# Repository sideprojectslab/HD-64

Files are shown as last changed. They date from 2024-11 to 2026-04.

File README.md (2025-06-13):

# HD-64

To **REPORT ISSUES** or to simply get in touch with the developer, please join the SPL [Discord](https://discord.gg/gJsCgebkDw) server.

[FULL README (PDF)](https://raw.githubusercontent.com/sideprojectslab/HD-64/main/doc/README.pdf)

HD-64 is an RF-modulator replacement for the Commodore-64 computer which features a Full-HD 50/60Hz Micro-HDMI video+audio output. Crucially, the HD-64 is not a replacement for the VIC-II, which still needs to be mounted on the motherboard

Instead of digitizing the VIC's analog video output signal, the HD-64 "sniffs" the C64's memory bus and recreates a pixel-perfect video output by means of emulation implemented on FPGA. The reconstructed video is then upscaled to Full-HD resolution, merged with the digitized audio from the SID, and sent out as HDMI.

<figure align="center" id="HD-64">
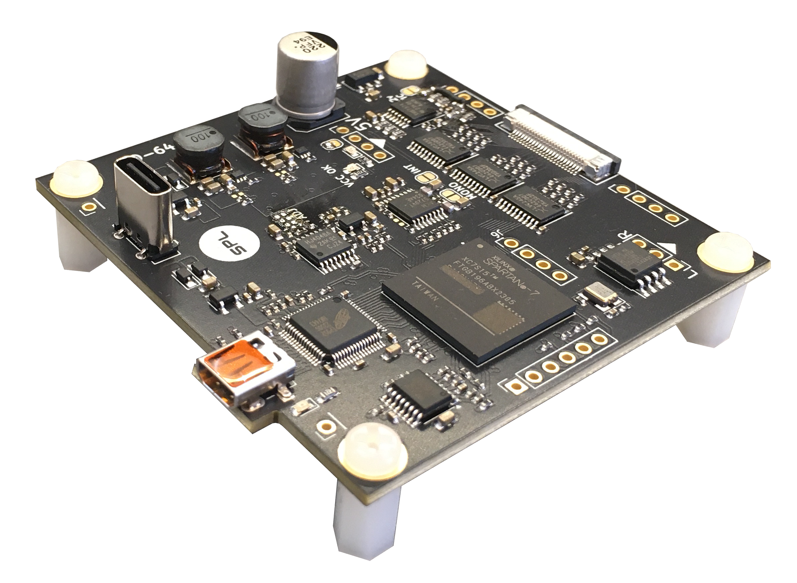
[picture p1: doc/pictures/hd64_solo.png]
	
	<figcaption>HD-64 Main Board</figcaption>
</figure>

<figure align="center" id="hd64_shortboard_back">
	
	<figcaption>HD-64 Short-Board Assembly</figcaption>
</figure>

<figure align="center" id="hd64_longboard">
	
	<figcaption>HD-64 Long-Board Assembly</figcaption>
</figure>

# 1. License
License information is included on top of all software source files as well as in all schematics. Files that do not contain explicit licensing information are subject to the licensing terms stated in the LICENSE.txt provided in the main project folder:

Unless stated otherwise in individual files, all hardware design Schematics, Bill of Materials, Gerber files and manuals are licensed under Creative Commons Attribution-NonCommercial-NoDerivatives 4.0 International. To view a copy of this license, visit http://creativecommons.org/licenses/by-nc-nd/4.0/

Unless otherwise stated in individual files, all software source files are Licensed under the Apache License, Version 2.0. You may obtain a copy of this license at http://www.apache.org/licenses/LICENSE-2.0

# 2. Disclaimer
All material is provided on an 'AS IS' BASIS, WITHOUT WARRANTIES OR CONDITIONS OF ANY KIND in accordance to the license deed applicable to each individual file.

# 3. Contributing
The only open source portion of the HD-64 firmware is the VIC-II emulation written in VHDL, with the rest of the source code not being made available. Even so, **anyone can contribute to changes to the VIC-II emulator, build and test the results without having to access the entire codebase, nor having to set up a local build system**. Builds run directly on the SPL build server and compilation outputs are delivered back to the developers through dedicated GitHub releases. Please find the [Developer's Guide](https://raw.githubusercontent.com/sideprojectslab/HD-64/main/doc/dev_guide.pdf) for detailed information on how to contribute to the project.

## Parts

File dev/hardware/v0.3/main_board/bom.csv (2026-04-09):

Comment | DNP | Designator | Footprint
GRM155R71H104KE14D |  | C1, C2, C3, C6, C10, C12, C14, C19, C26, C27, C28, C29, C30, C31, C32, C33, C37, C40, C44, C45, C53, C59, C62, C63, C64, C69, C72, C79, C80, C81, C82, C83, C85, C90, C94 | eas_cdb_capacitor:C_0402_1005Metric
GRM188R61A106ME69D |  | C4, C5, C7, C11, C13, C15, C16, C17, C23, C24, C25, C36, C41, C46, C48, C49, C52, C55, C56, C58, C68, C71, C76, C77, C78, C84, C86, C97, C98 | eas_cdb_capacitor:C_0603_1608Metric
C1608C0G1H103JT000N |  | C8, C9 | eas_cdb_capacitor:C_0603_1608Metric
GRM155R61C105KE01D |  | C18, C20, C21, C35, C39, C42, C60, C65, C67, C70, C73, C74, C75 | eas_cdb_capacitor:C_0402_1005Metric
GRM155R61A474KE15D |  | C34, C38, C61 | eas_cdb_capacitor:C_0402_1005Metric
EEE-FP1V221AP |  | C51 | eas_cdb_capacitor:CP_Elec_8x6.9
CL21A476MQYNNNG |  | C66, C87, C88, C89, C91, C92 | eas_cdb_capacitor:C_0805_2012Metric
GCM1555C1H100JA16D |  | C96 | eas_cdb_capacitor:C_0402_1005Metric
B5817WS |  | D1, D3, D5, D8, D9 | eas_cdb_diode:D_SOD-323_HandSoldering
LTST-C191KGKT |  | D2, D6, D10 | eas_cdb_opto:LED_0603_1608Metric
AFC07-S24FCA-00 |  | J1 | eas_cdb_connector_generic:AFC07-S24FCA-00
TYPE-C 16P LTH8.8 |  | J4 | eas_cdb_connector_generic:CONN_GSB1CA11101DSHR_AMP
HDMI-101L |  | J11 | eas_cdb_connector_generic:HDMI_Micro-D_Molex_46765-2x0x
FNR6045S100MT |  | L1, L2 | eas_cdb_inductor:IND_1255AY-xRxN=P3
DMP1045U-7 |  | Q1 | eas_cdb_mosfet:SOT-23
RC0402FR-0722RL |  | R1, R2, R11, R12, R63, R70, R107, R126, R127 | eas_cdb_resistor:R_0402_1005Metric
RC0402FR-0710KL |  | R3, R8, R13, R17, R21, R22, R30, R31, R32, R35, R41, R42, R45, R46, R52, R53, R57, R58, R60, R61, R62, R71, R114, R115, R116, R122, R123, R124, R125 | eas_cdb_resistor:R_0402_1005Metric
RC0402FR-072K2L |  | R4, R5, R39, R40, R48, R51, R98, R103, R105, R106 | eas_cdb_resistor:R_0402_1005Metric
RC0603FR-073K3L |  | R6 | eas_cdb_resistor:R_0603_1608Metric
RC0603FR-07680RL |  | R7, R28, R65 | eas_cdb_resistor:R_0603_1608Metric
RC0603FR-07270RL |  | R9, R128 | eas_cdb_resistor:R_0603_1608Metric
RC0603FR-07470RL |  | R10 | eas_cdb_resistor:R_0603_1608Metric
RC0402FR-075K1L |  | R14, R18 | eas_cdb_resistor:R_0402_1005Metric
RC0402FR-07100KL |  | R15 | eas_cdb_resistor:R_0402_1005Metric
RC0603FR-07220RL |  | R19 | eas_cdb_resistor:R_0603_1608Metric
RC0402FR-071KL |  | R23, R24, R36, R96, R97, R99, R100, R101, R108 | eas_cdb_resistor:R_0402_1005Metric
RC0603FR-0775RL |  | R25, R26, R27 | eas_cdb_resistor:R_0603_1608Metric
RC0402FR-076K8L |  | R29 | eas_cdb_resistor:R_0402_1005Metric
RC0402FR-074K7L |  | R33, R34, R104 | eas_cdb_resistor:R_0402_1005Metric
RC0402FR-07820RL |  | R37 | eas_cdb_resistor:R_0402_1005Metric
RC0402FR-0747KL |  | R38, R44, R47 | eas_cdb_resistor:R_0402_1005Metric
RC0402FR-072M2L |  | R43 | eas_cdb_resistor:R_0402_1005Metric
RC0402FR-0733KL |  | R50 | eas_cdb_resistor:R_0402_1005Metric
0402WGF1213TCE |  | R54 | eas_cdb_resistor:R_0402_1005Metric
RC0402FR-0727KL |  | R55 | eas_cdb_resistor:R_0402_1005Metric
RC0603FR-071KL |  | R64, R68 | eas_cdb_resistor:R_0603_1608Metric
RC0603FR-07330RL |  | R66 | eas_cdb_resistor:R_0603_1608Metric
RC0603FR-07100RL |  | R67 | eas_cdb_resistor:R_0603_1608Metric
RC0402FR-07100RL |  | R72, R73, R74, R75, R76, R77, R78, R79, R80, R81, R82, R83, R84, R85, R86, R87, R88, R89, R90, R91, R92, R93, R94, R118, R119, R120, R121 | eas_cdb_resistor:R_0402_1005Metric
74LVC245APW,118 |  | U1, U2, U3 | eas_cdb_ic_misc:SSOP-20_4.4x6.5mm_P0.65mm
XC7S15-1FTGB196C |  | U4 | eas_cdb_fpga:BGA196C100P14X14_1500X1500X155N
AZ1117CR-3.3TRG1 |  | U5 | eas_cdb_power:SOT-89-3
TPS62A02ADRLR |  | U6, U17 | eas_cdb_power:SOT-563
LR8103B-T18 |  | U7, U8 | eas_cdb_power:TSOT-23-5
EP952 |  | U9 | eas_cdb_ic_misc:LQFP-64_7x7mm_P0.4mm
TLV9061IDBVR |  | U10 | eas_cdb_opamp:SOT-23-5
CD74HC4046APWR |  | U11 | eas_cdb_oscillator:TSSOP-16_4.4x5mm_P0.65mm
THS7374 |  | U13 | eas_cdb_opamp:TSSOP-14_4.4x5mm_P0.65mm
MX25L6433FM2I-08G |  | U14 | eas_cdb_ic_misc:SOIC-8W_5.3x5.3mm_P1.27mm
AK5720VT |  | U15 | eas_cdb_ad_da:TSSOP-16_4.4x5mm_P0.65mm
OT322550MJBA4SL |  | U16 | eas_cdb_oscillator:Oscillator_SMD_4Pin_3.2x2.5mm
CH340E |  | U21 | eas_cdb_ic_misc:MSOP-10_3x3mm_P0.5mm

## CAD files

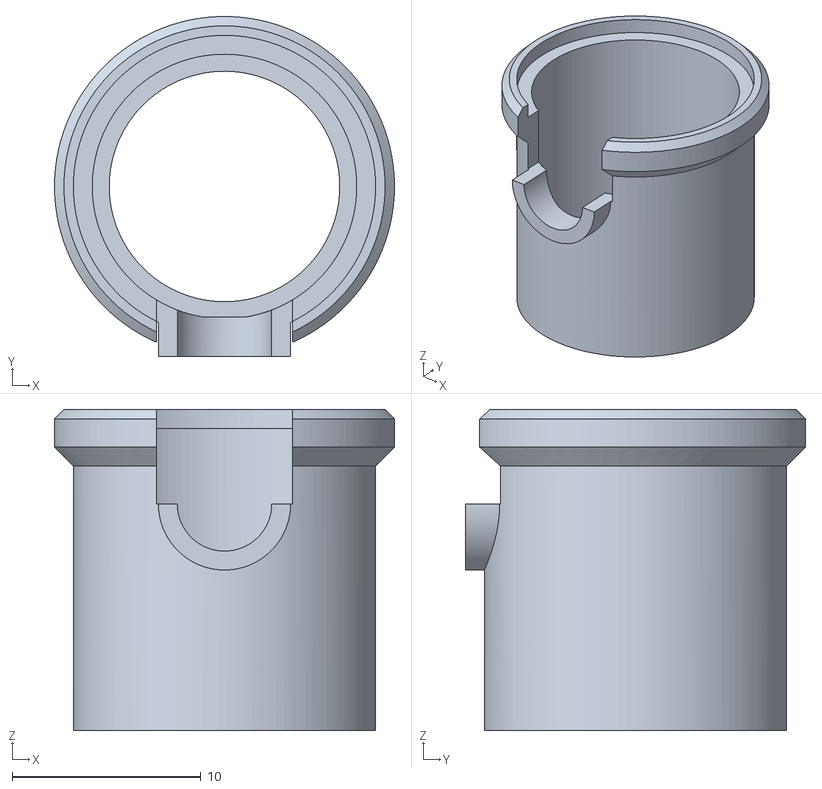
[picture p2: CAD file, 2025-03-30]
dev/mechanical/uii-custom-din/U2-DIN-bot.stl
18.0 x 18.0 x 17.0

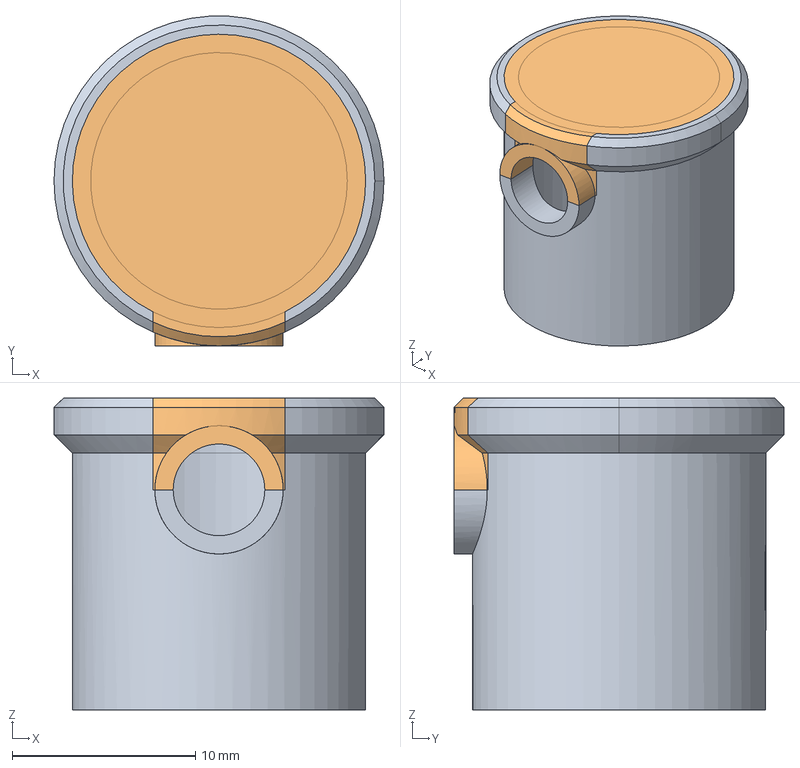
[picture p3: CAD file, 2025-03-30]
dev/mechanical/uii-custom-din/U2-DIN.FCStd
18.0 x 18.0 x 17.0 mm
bot
top

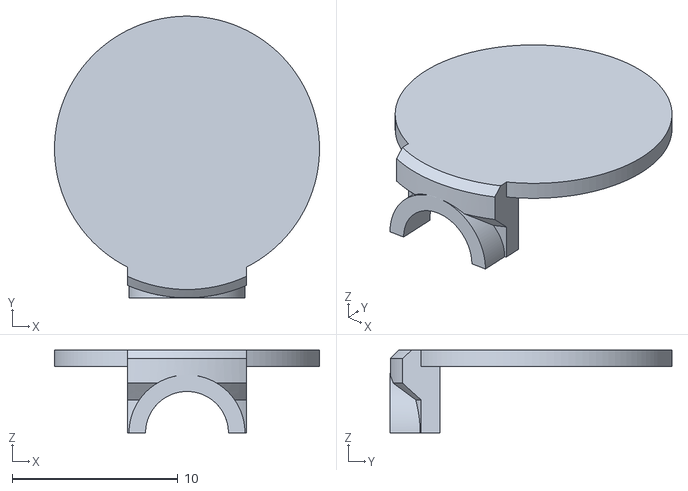
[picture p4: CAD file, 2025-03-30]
dev/mechanical/uii-custom-din/U2-DIN-top.stl
16.0 x 17.0 x 5.00

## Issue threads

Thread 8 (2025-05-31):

Improved 4:3 scaling

mvbhz, 2025-05-31:
Hello

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

Could you improve the 4:3 scaling? In the screenshot below I have shown the program "circle" which draws perfect circles. Here you can see that the geometry is incorrect, i.e. the image in 4:3 is a bit too narrow. Could this be improved?

sideprojectslab, 2025-06-08:
Hello, sorry for the late reply. So it would appear that those circles are indeed thinner than they should be. However what do you see on the analog output (composite/s-video)? are those perfectly round there? because I believe I have used the "nominal" pixel aspect ratio for the C64, which is not a perfect square as far as I remember. Though I might have slightly missed the exact ratio

mvbhz, 2025-06-12:
I connected the Commodore 64 via analog signal and at 4:3 the wheels are not perfect either:

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

Another thing, pixels are not perfectly mapped in HDMI - compared to e.g. VIC-II-dizer they are slightly blurred at the edges:

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

If you could improve this, especially the aspect ratio (circles) I would be grateful.

sideprojectslab, 2025-06-12:
The latest version is v0.12 [link](https://github.com/sideprojectslab/HD-64/releases/tag/fw-0.12) you will have to update the configuration utility too, as is outlined in the user manual (see here for the latest version of that too [link](https://raw.githubusercontent.com/sideprojectslab/HD-64/main/doc/README.pdf)). With the new configuration utility you will be able to enable integer scaling, which will improve the clarity of your pixels, at least vertically.

From what I can tell the VIC-II-dizer uses a larger portion of the screen compared to the regular 4:3 to achieve square pixels (more like 5:3), which is the only way to achieve horizontal integer scaling without losing the lateral borders outside of the display area. This would possibly mean adding an intermediate step between "narrow screen" and "wide screen".

I'll give this some thought and see what it would mean to add this feature, but if it happens it will be in a few months, as there are more pressing issues to solve right now.

mvbhz, 2025-06-19:
OK, I updated the firmware to version 0.12. I enabled the "INTEGER SCALING" option, but that didn't solve the problem of blurred edges. The only thing I noticed was that the frame size changed. I also tried toggling other options (GREY DOT BUG,   ZOOM, VIDEO MODE), but that didn't help either.

Apart from what I've just noticed, there are slightly visible horizontal lines on the background.

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

It would be worth fixing this, but I'd most like an option that lets you set an "alternative" image geometry.

sideprojectslab, 2025-06-19:
With integer scaling enabled horizontal edges should be perfect and you should only see blur on the vertical ones. But that might actually be because there is a small amount of blur always enabled. It might make sense to disable it when selecting integer scaling. I'll see if that can be done easily.

On a related note, please consider joining the Discord server as I will disable Github issues for this repo soon. I provide all support on discord and there are a lot of people with whom you can share opinions.

I want to give you an advice and please don't take it the wrong way. Since I have sold about 350 devices and you seem to be the only one who ever even noticed this little amount of blur, perhaps you should try to use the computer in a "normal" way for some time, so with your eyes at a reasonable distance from the screen and doing something interesting other than looking at the start screen. Once you take your mind off these details you might be able to enjoy the product like so many other people are doing :)

mvbhz, 2025-06-19:
I understand. Someone once wrote to me that in the retro era we had such an image, but today, in the new era, we don't have to watch such an image. I know that these are very individual experiences and I respect people who like the "old type" image, but for me the nostalgia for the "CRT" image has long since passed.

So if you have the time and desire to create a square pixel option, I will be grateful. If not - I will not be offended.

sideprojectslab, 2025-06-23:
I think I will do it, but I am strapped at the moment, I should have some time in a couple of months to really focus on it. I have an idea on how to do it at least.

mvbhz, 2025-06-23:
OK, then I'll wait for information. Thanks.

Closed 2025-06-23.

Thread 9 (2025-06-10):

HDMI output only lasts about 60 seconds

The-Spirit, 2025-06-10:
On my monitor the HDMI signal only lasts about 60 seconds, the the picture is gone and the indicator led is off on the HD-64 board.
It will not come back on, even if I power cycle the C64.
But if it's been off for a while and I turn it on (both, the C64 and monitor) it will work again for about 60 seconds.
Any ideas on what the problem can be?

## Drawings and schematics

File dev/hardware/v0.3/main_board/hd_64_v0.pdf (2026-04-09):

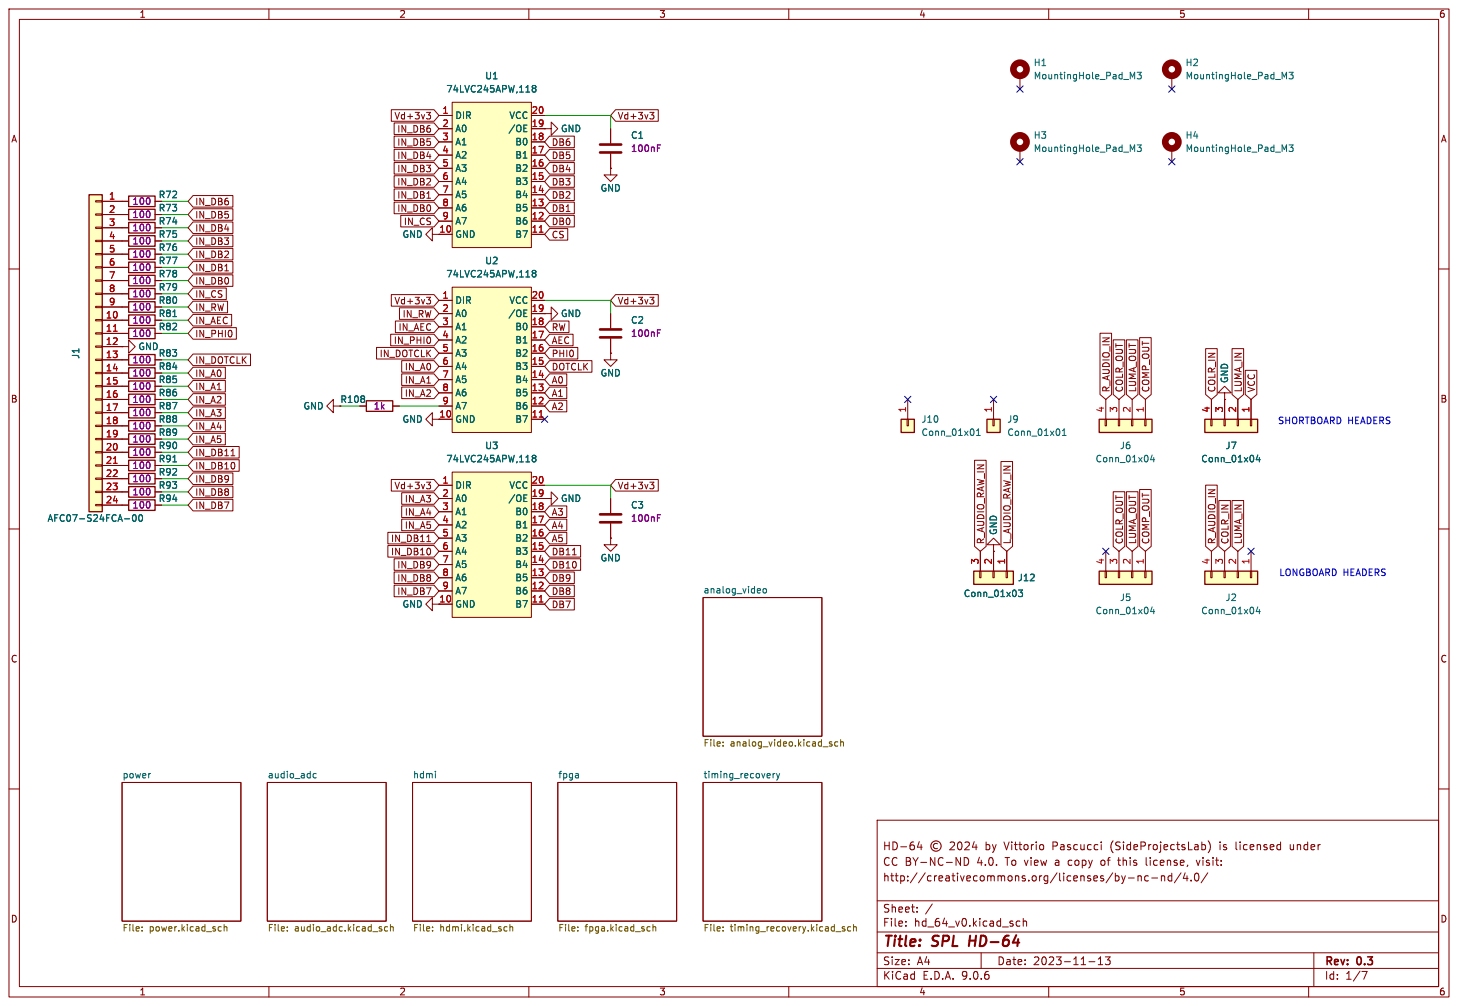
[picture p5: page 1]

Id: 1/7 Title: SPL HD-64

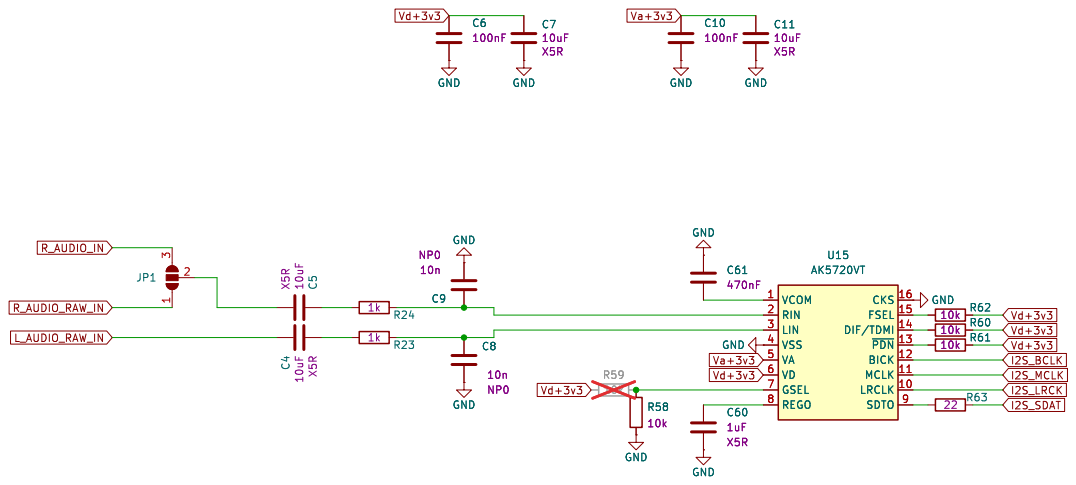
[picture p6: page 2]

Id: 2/7 Title: SPL HD-64

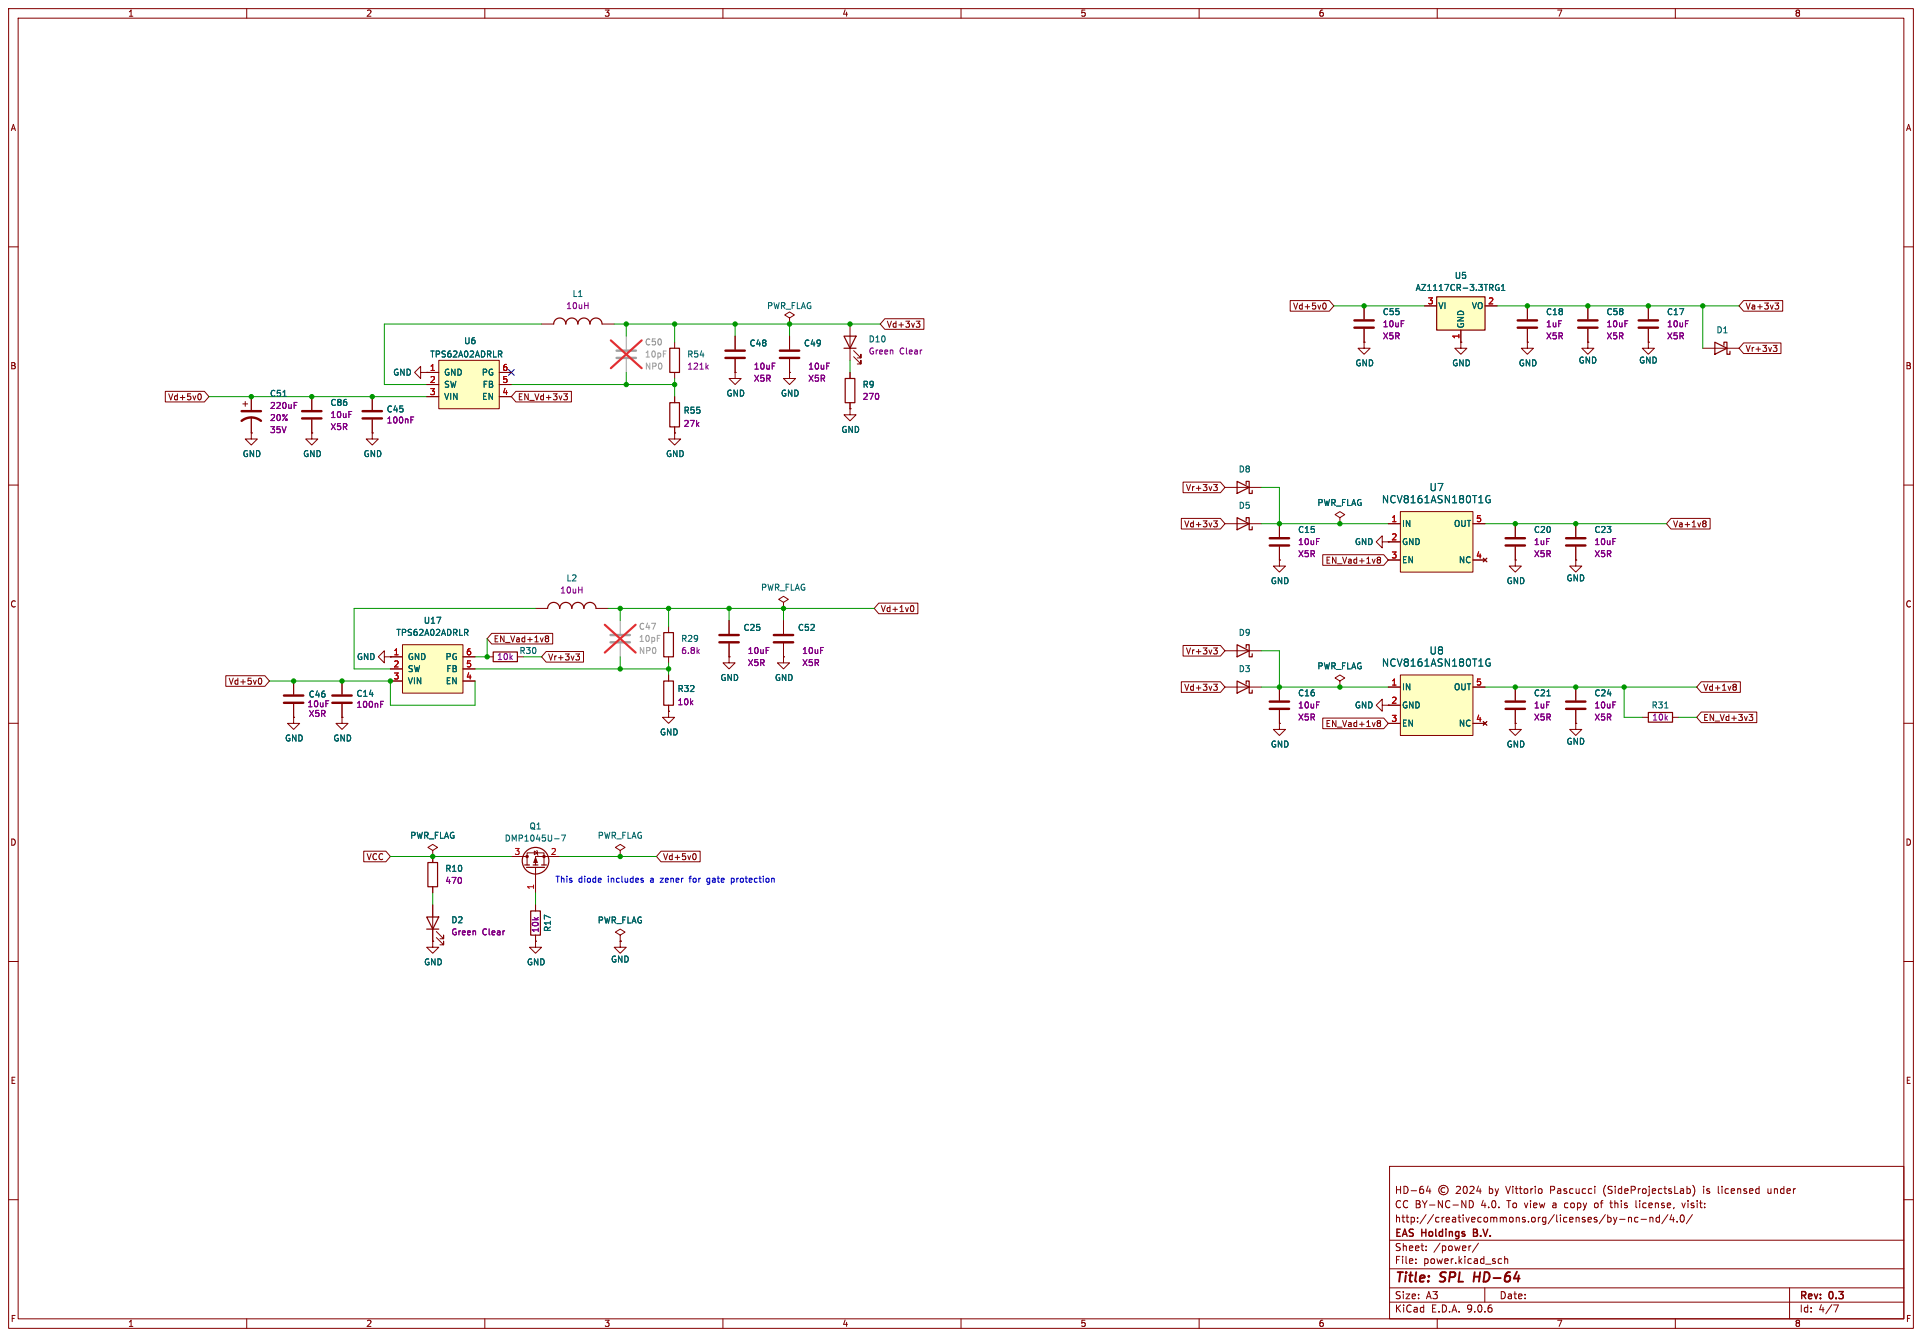
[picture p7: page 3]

Id: 4/7 Title: SPL HD-64

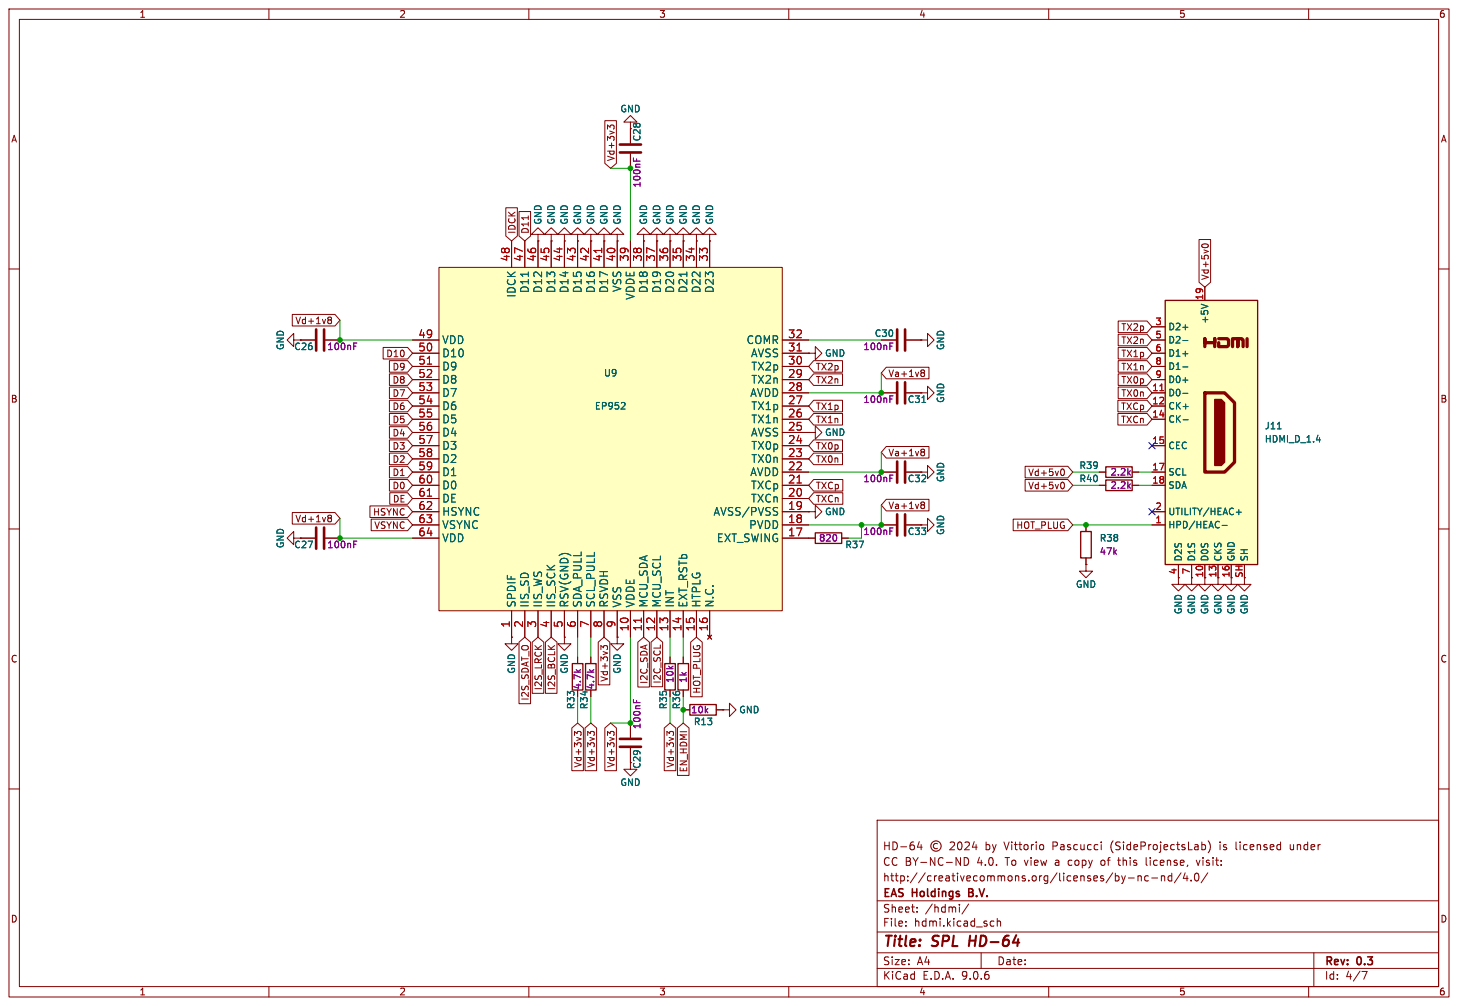
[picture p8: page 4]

J11 HDMI_D_1.4 GND GND GND GND

Id: 4/7 Title: SPL HD-64

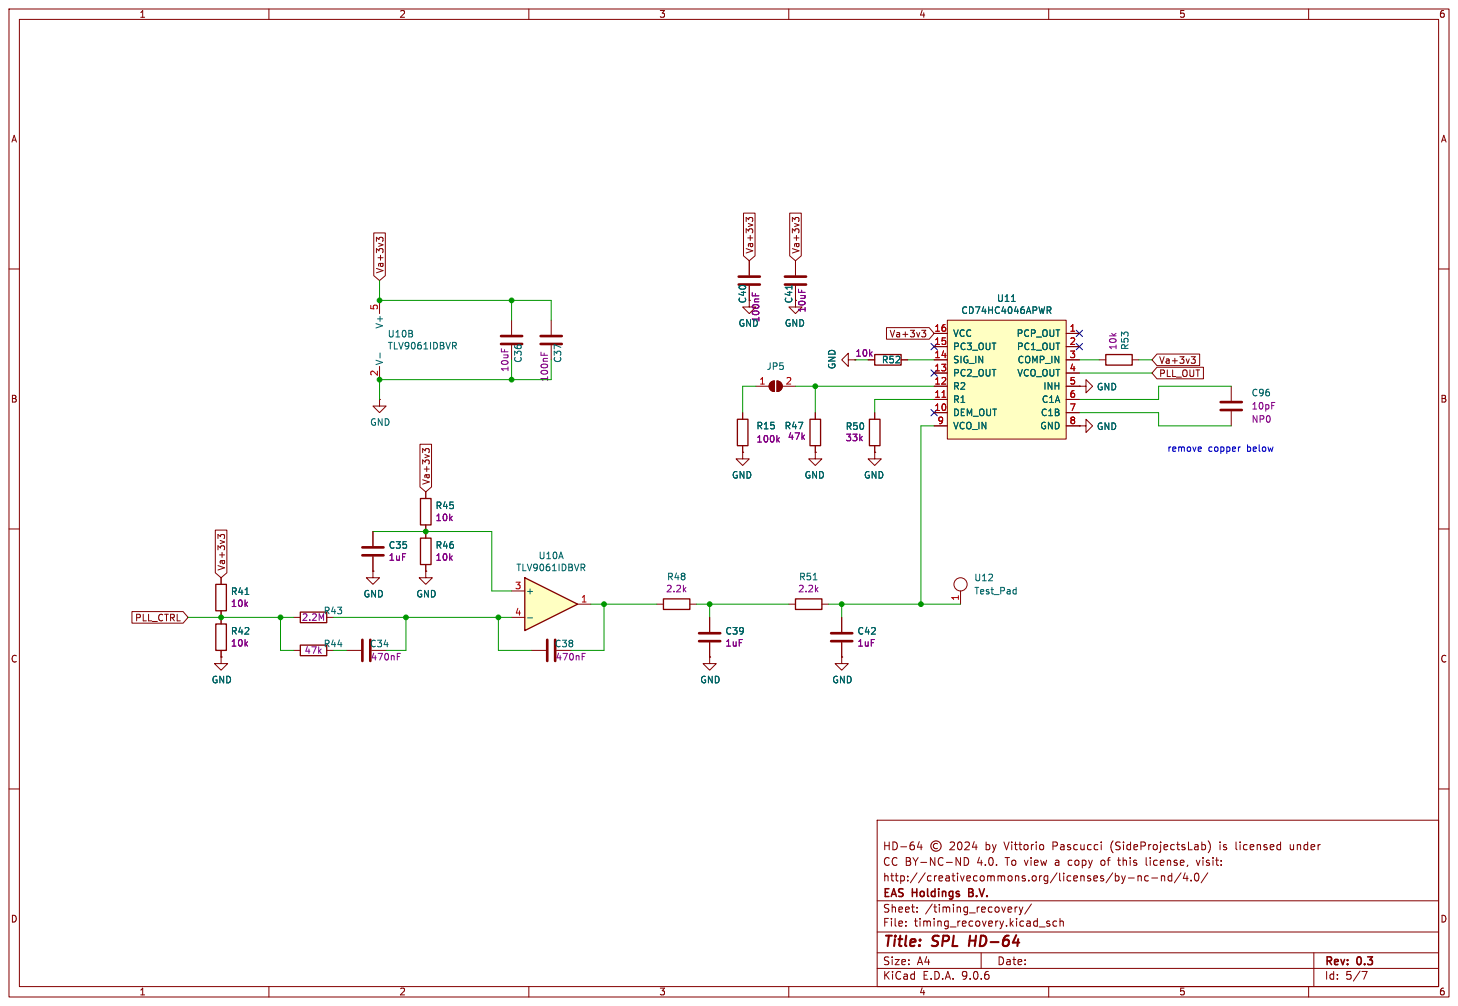
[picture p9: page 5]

remove copper below GND

Id: 5/7 Title: SPL HD-64

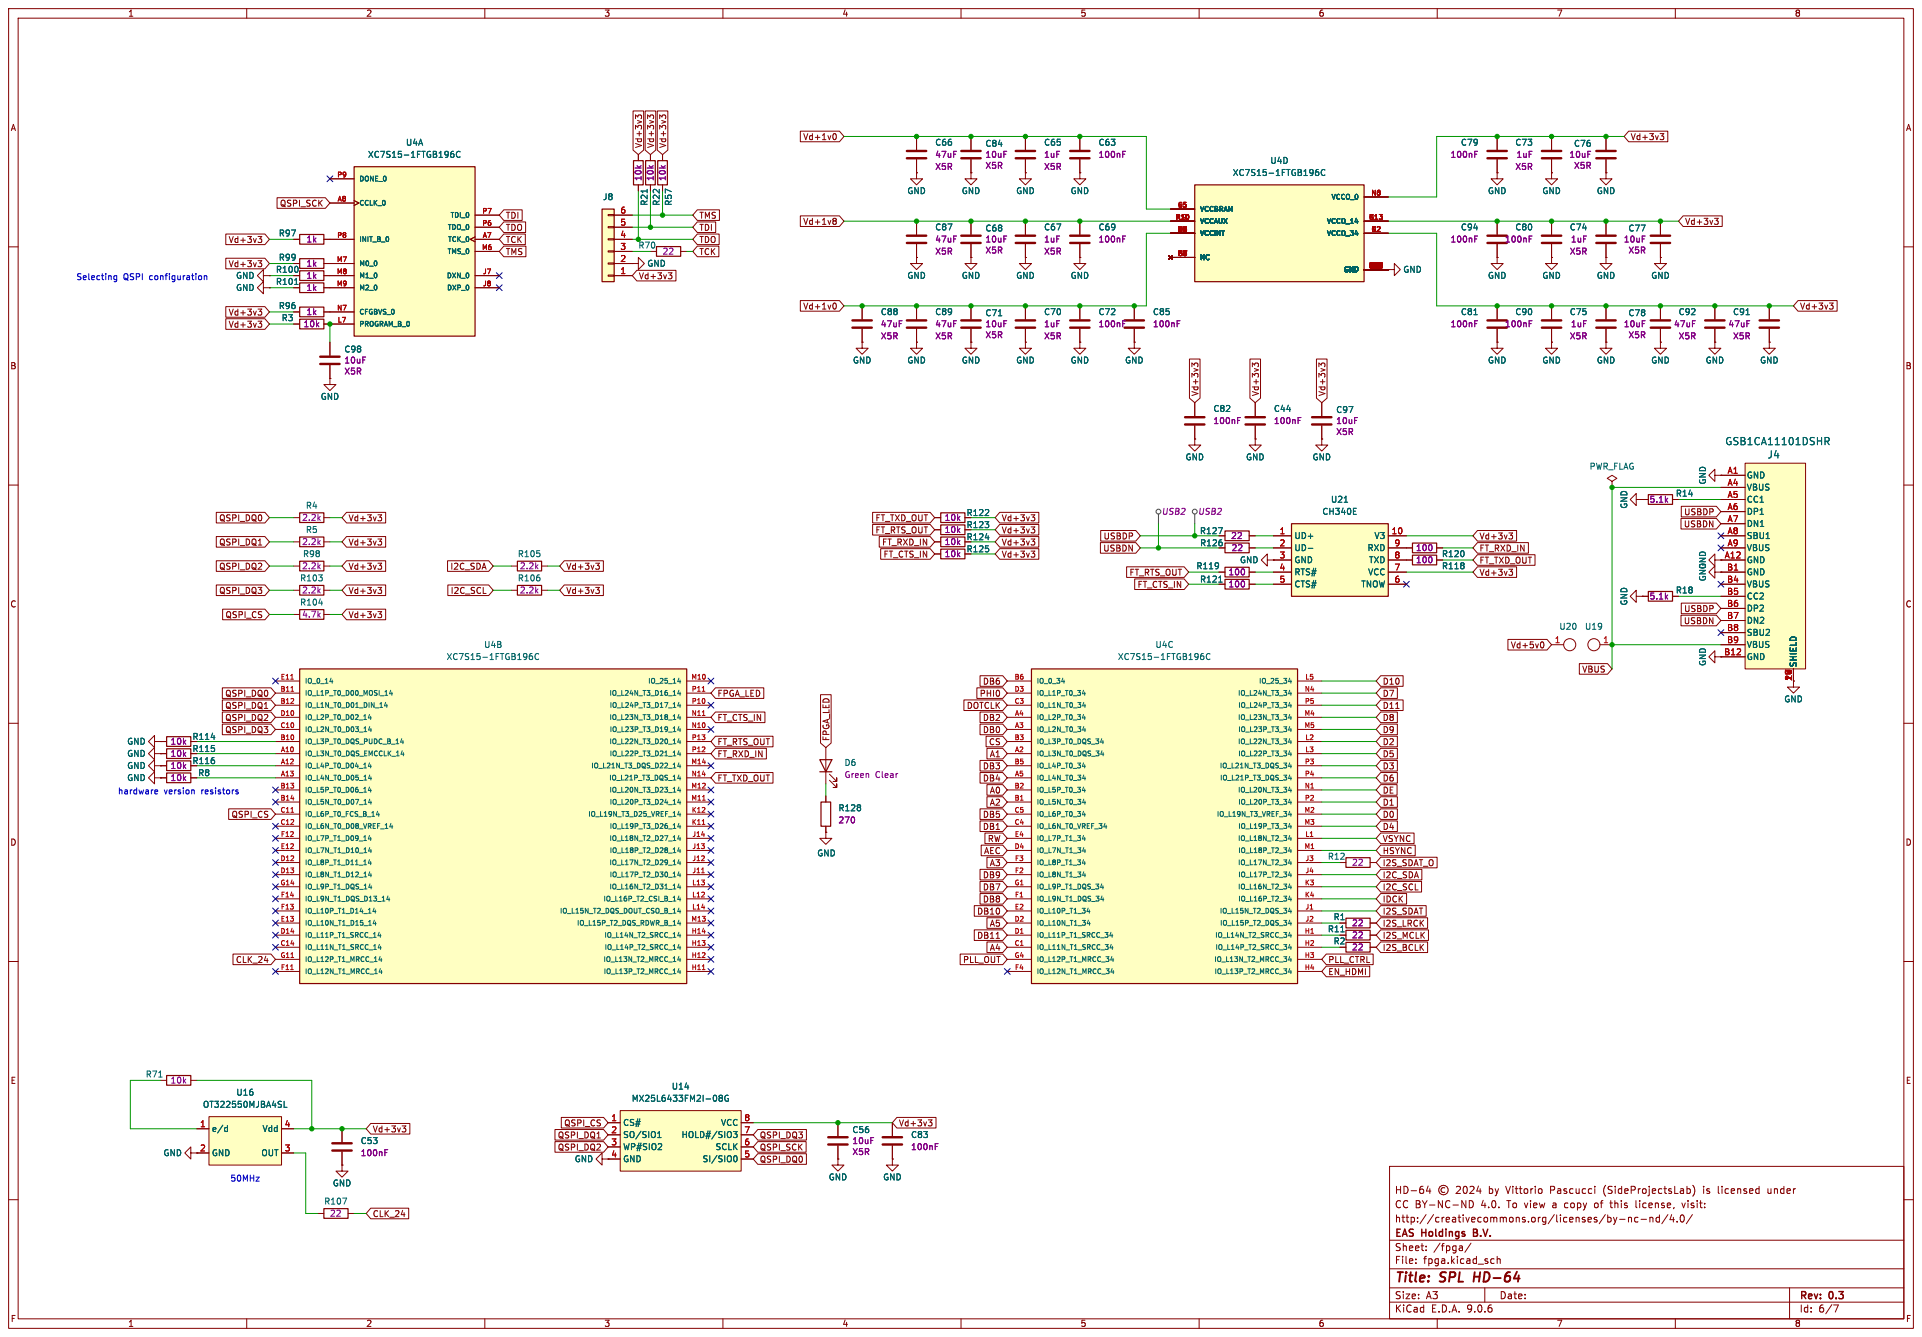
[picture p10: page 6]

Id: 6/7 Title: SPL HD-64

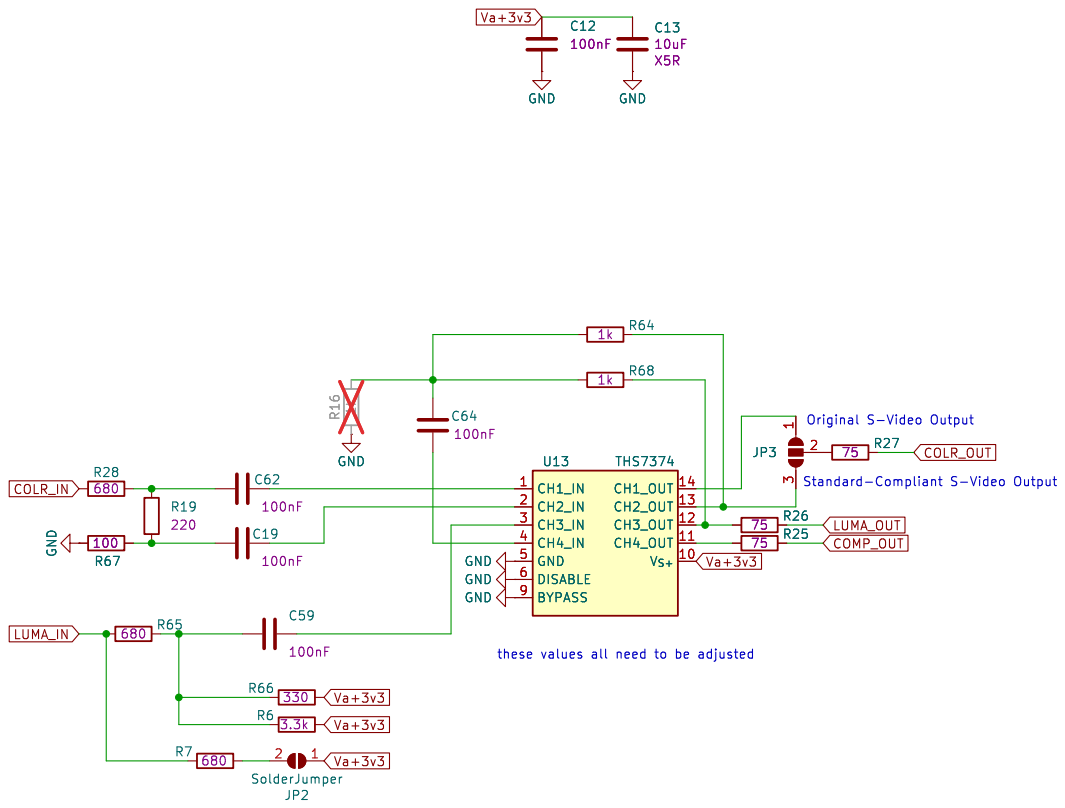
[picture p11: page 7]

Id: 7/7 Title: SPL HD-64

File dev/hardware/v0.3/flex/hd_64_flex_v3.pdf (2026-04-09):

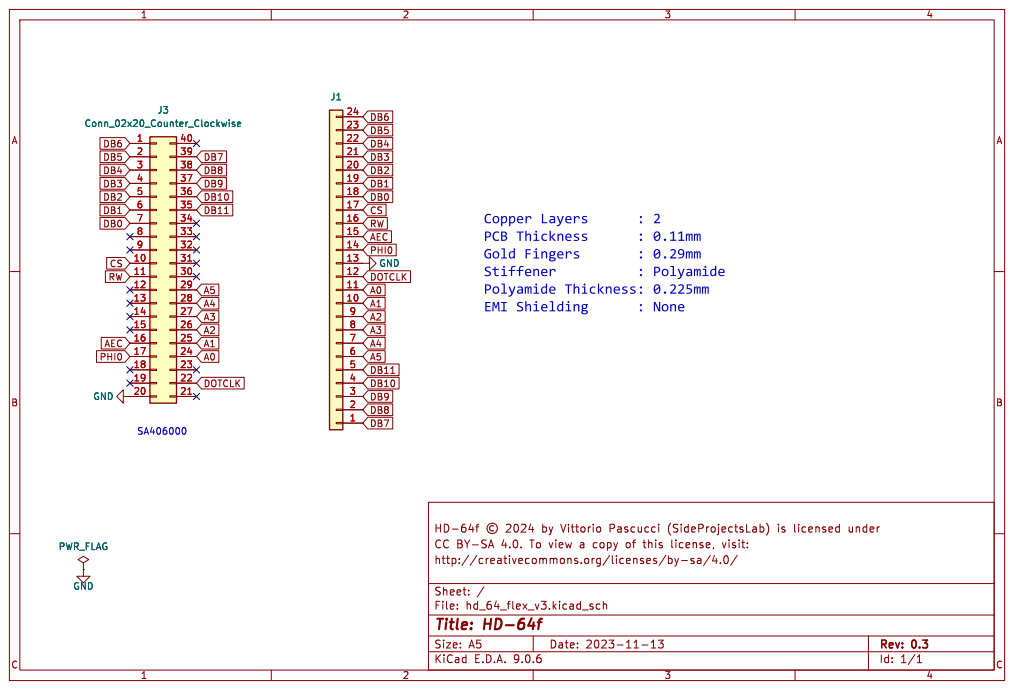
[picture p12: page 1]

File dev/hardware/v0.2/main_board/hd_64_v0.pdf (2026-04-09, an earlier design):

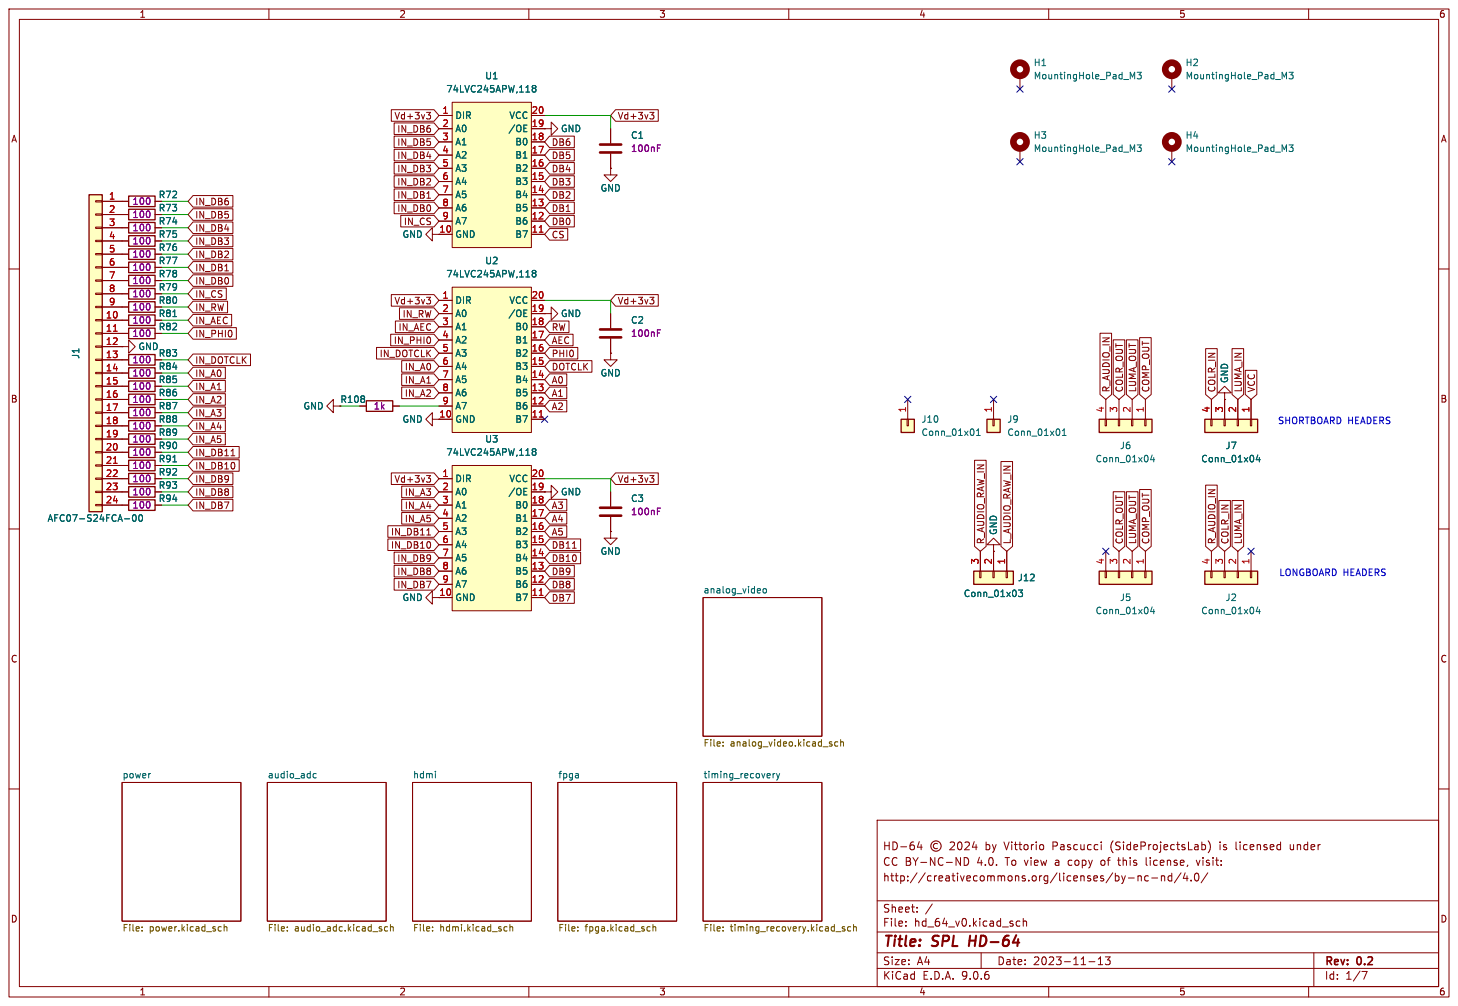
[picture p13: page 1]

Id: 1/7 Title: SPL HD-64


Id: 2/7 Title: SPL HD-64

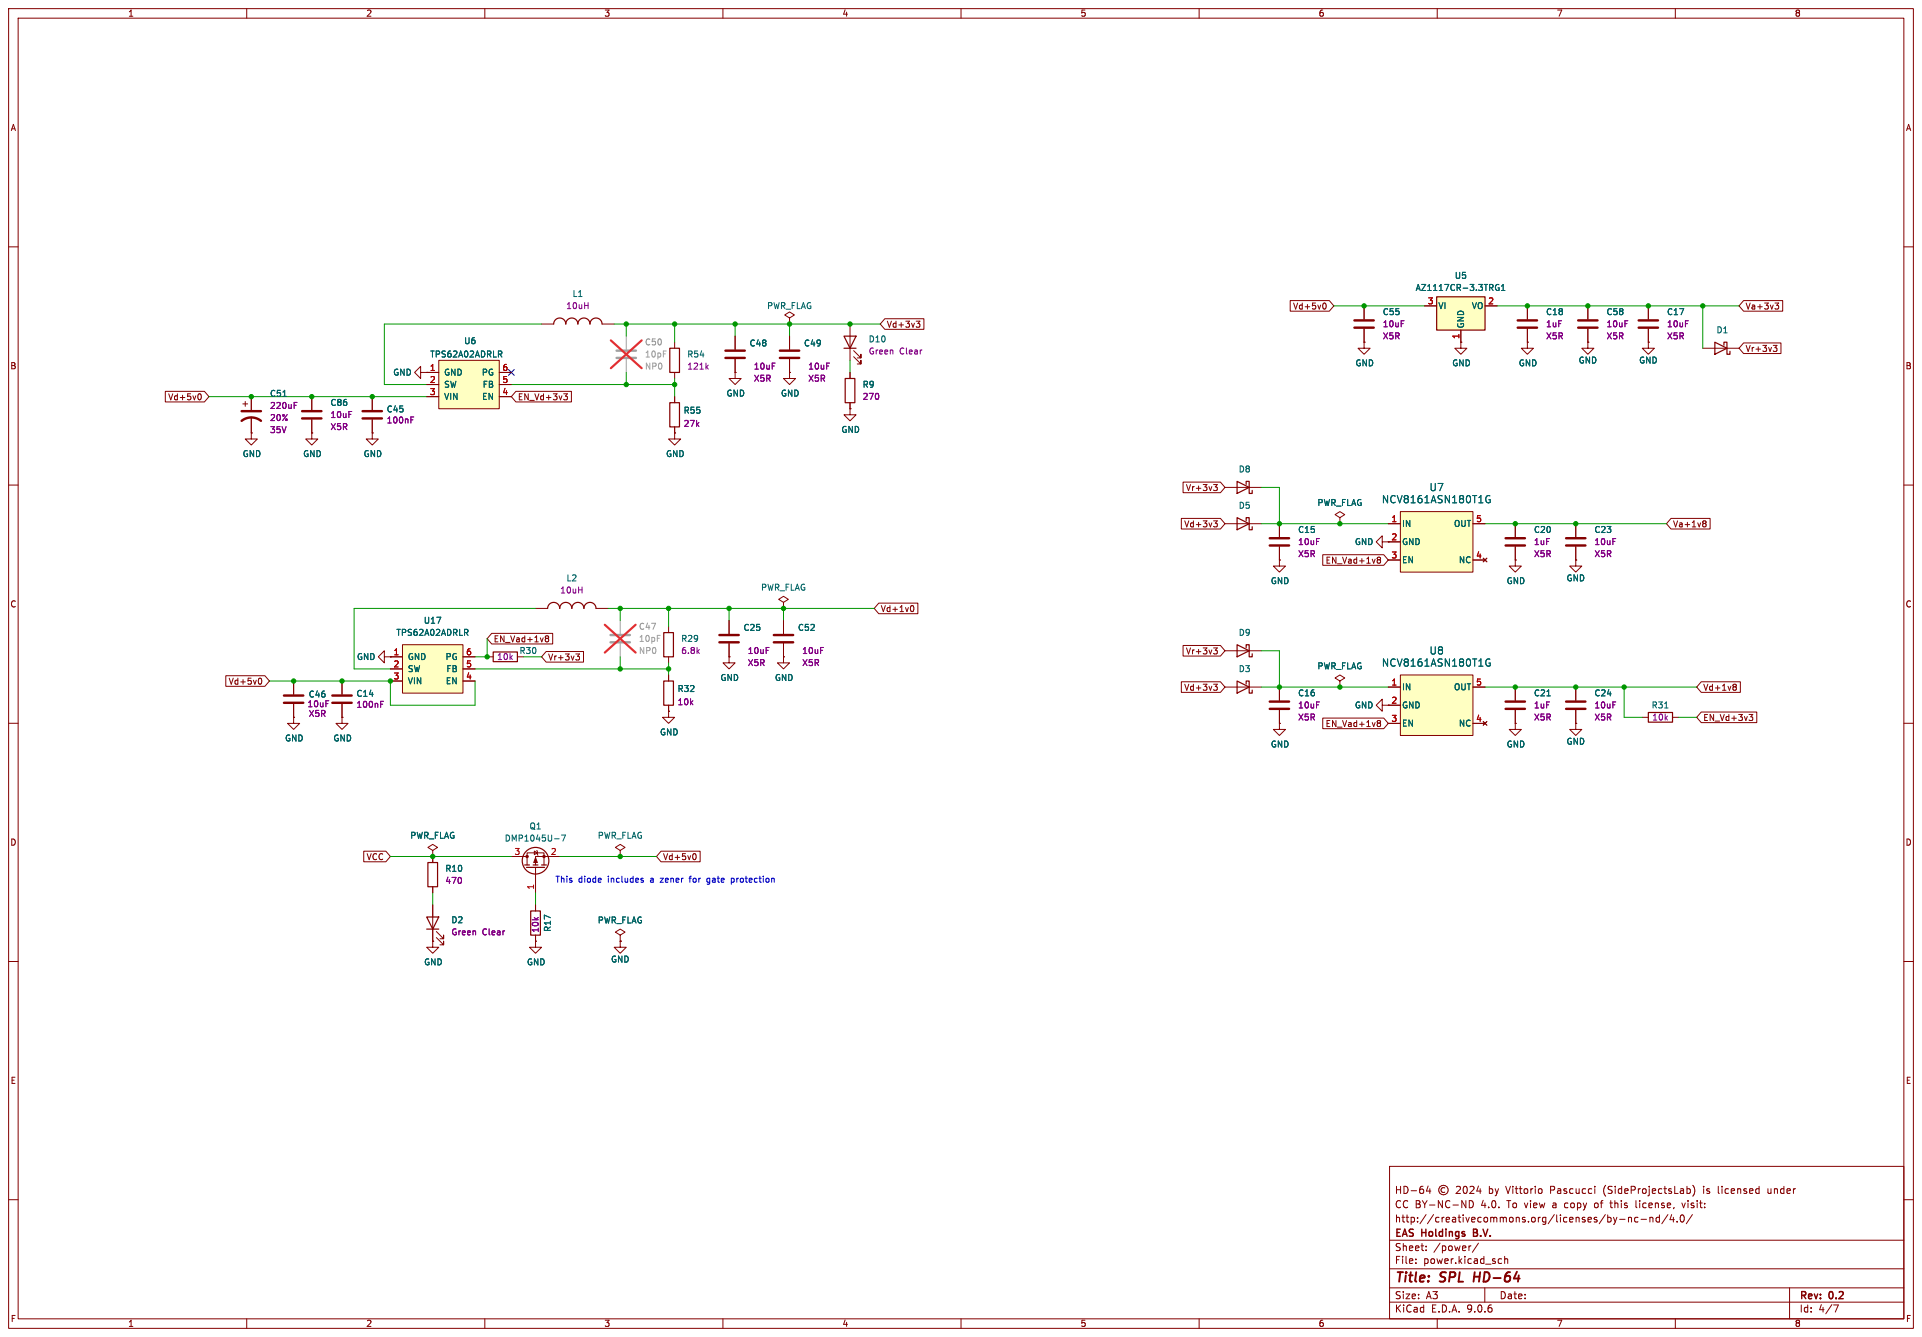
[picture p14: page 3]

Id: 4/7 Title: SPL HD-64

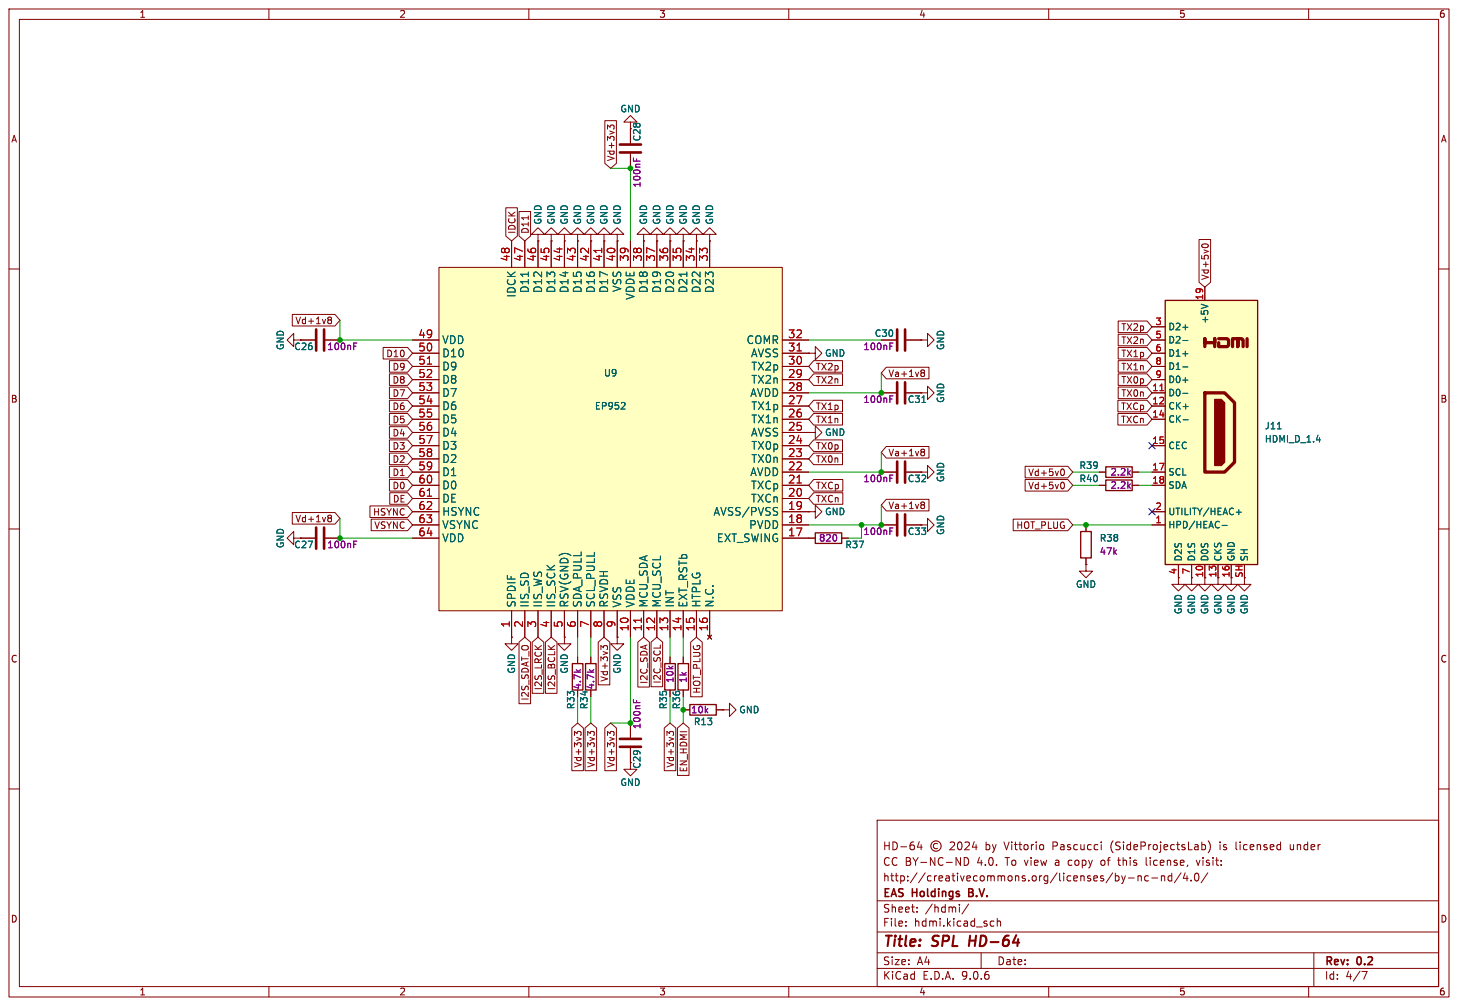
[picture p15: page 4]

J11 HDMI_D_1.4 GND GND GND GND

Id: 4/7 Title: SPL HD-64

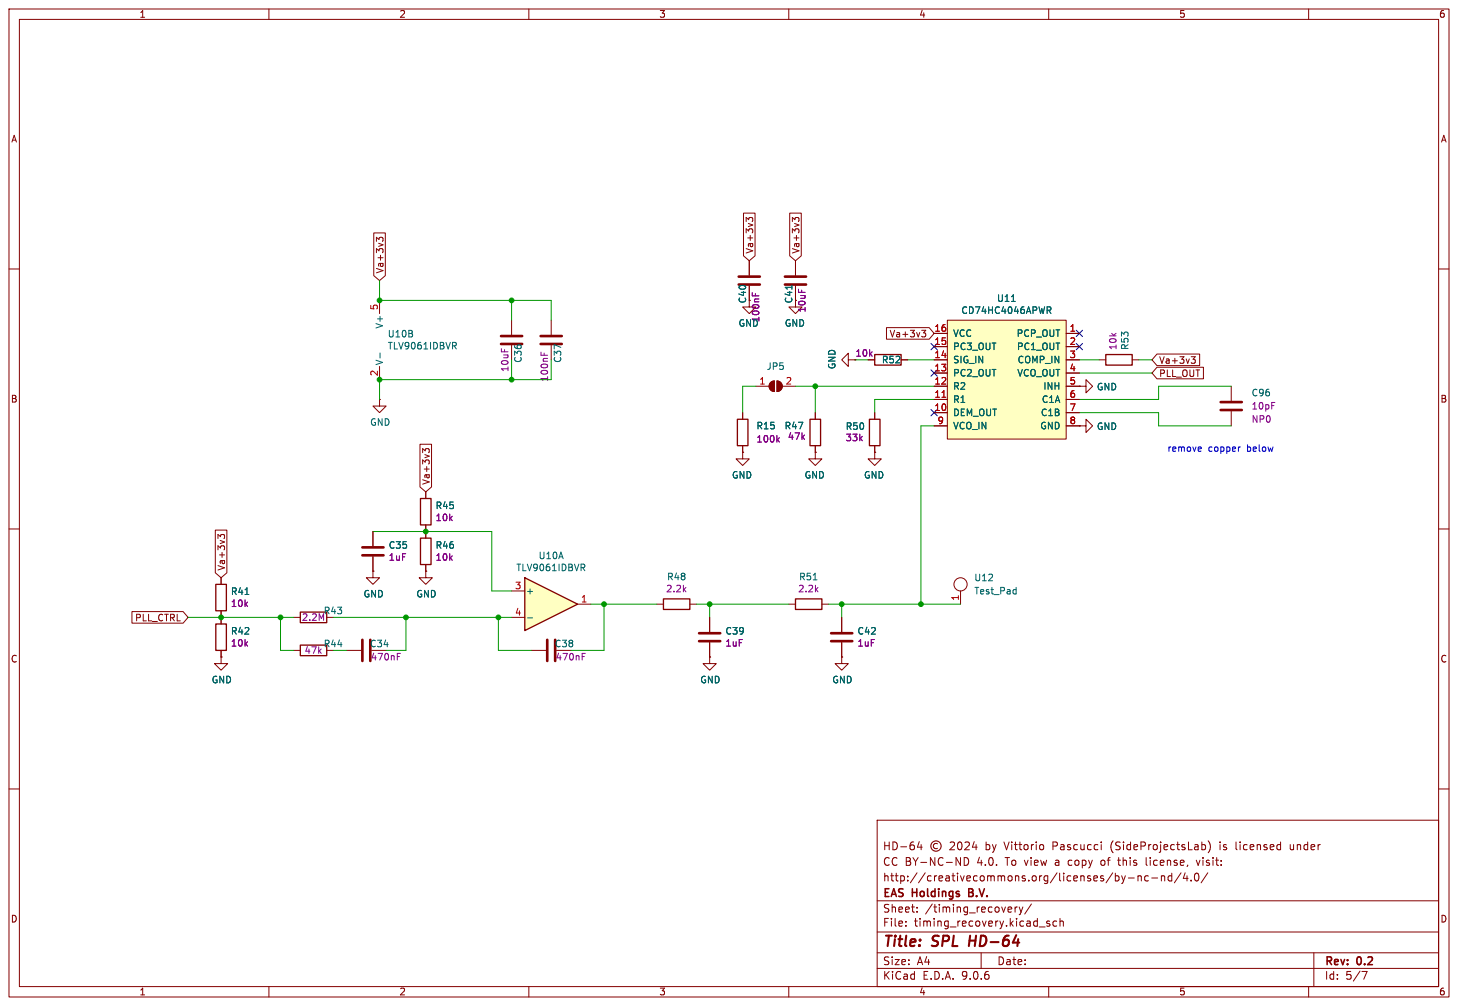
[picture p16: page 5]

remove copper below GND

Id: 5/7 Title: SPL HD-64


Id: 6/7 Title: SPL HD-64


Id: 7/7 Title: SPL HD-64

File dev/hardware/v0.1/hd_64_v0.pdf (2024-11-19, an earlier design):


Id: 1/7 Title: SPL HD-64


Id: 2/7 Title: SPL HD-64


Id: 4/7 Title: SPL HD-64


Id: 4/7 Title: SPL HD-64


Id: 5/7 Title: SPL HD-64


Id: 6/7 Title: SPL HD-64


COMP_OUT Va+3v3 Va+3v3 Va+3v3 Va+3v3

Id: 7/7 Title: SPL HD-64

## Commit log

2024-11-18 added hw design files
    [bom.csv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]
2024-11-19 fixed license link in schematic
2025-01-05 updated pre-release design files
    [bom.csv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]
2025-02-01 restructuring repo in preparation for production run
    [bom.csv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]
2025-02-12 uploaded corrected schematic & gerbers
    [bom.csv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]
2025-02-13 updated design files and documented chroma amplitude fix
    [bom.csv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]
2025-03-17 added press-fit interleaver-flex schematic & gerbers (free for commercial purposes)
    [bom.csv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]
2025-03-25 added stl files for improved floppy connector for Ultimate-II cartridges, that does not interfere with the HDMI cable
    [U2-DIN-bot.stl, U2-DIN-top.stl, U2-DIN.FCStd]
2025-06-13 Improved HDMI timing and added debug capabilities
    [bom.csv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]
2025-10-04 added instructions to assemble the press-fit interleaver
2025-10-10 removed interleaver assembly pictures as they depict the cable in the wrong direction. Will be re-uploaded soon with the correct images
2025-10-10 corrected interleaver assembly documentation
2025-11-26 updated gerbers
    [bom.csv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]
2025-11-26 better flex-cable gerber with narrower holes for better contact when pressing
    [hd_64_flex_v3-B_Cu.gbr, hd_64_flex_v3-B_Fab.gbr, hd_64_flex_v3-B_Mask.gbr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]
2025-12-20 Uploaded HW version v0.3 with replaced USB-UART converter
    [bom.csv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]
2026-08-12 updated manual
    [U2-DIN-bot.stl, U2-DIN-top.stl, U2-DIN.FCStd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]
